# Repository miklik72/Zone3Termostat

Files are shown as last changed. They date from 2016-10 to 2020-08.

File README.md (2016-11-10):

# Zone3Termostat
3 zone wireless termostat with 433MHz sensors T25

In project based on Arduino UNO I'm using 3 wireless 433MHz sensors Sencor T25 for control one boiler by relay.
Possible is use 5 programs with 6 steps per day with own temperature. Implemented is also RTC for use real time.
Each zone is possible independent turn on or off. For zone is possible also set date and time for delay start.
Here is used also LCD1602 ROBO shiels with 5 buttons + reset.

For sensors T25 I'm using my own library  https://github.com/miklik72/SensorT25.

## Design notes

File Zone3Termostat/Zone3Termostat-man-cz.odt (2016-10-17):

1. Základní obrazovka Tlačítka

Set číslo pokoje teplota program topí

1

3

2

Zpět

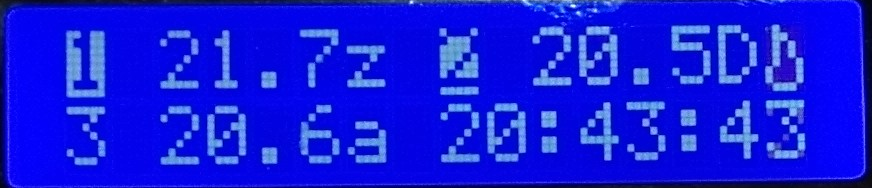
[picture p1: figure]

čas

  1. číslo pokoje: 1 – 3 , inverzně = zapnuto
  2. Teplota: teplota v pokoji v °C
  3. Program: a-e = pokoj netopí, A-E = pokoj topí, z = zpožděné zapnutí
  4. Topí: kotel je sepnutý
  5. Čas: aktuální čas

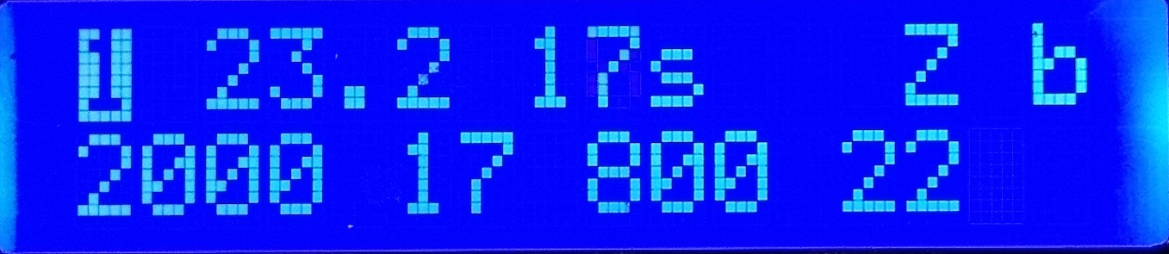
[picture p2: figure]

2. Nastavení pokoje
  1. Stiskni tlačítko čísla pokoje (1 – 3) pro obrazovku pokoje
  2. Zapnutí pokoje

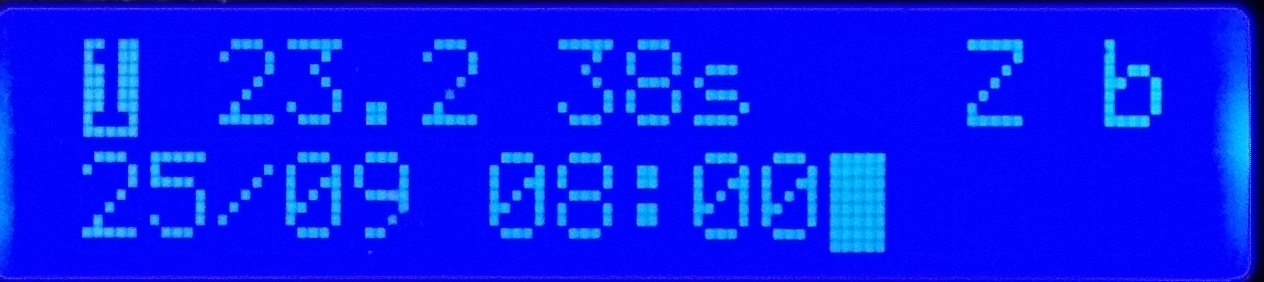
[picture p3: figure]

    1. Stiskni Set pro obrazovku zapnutí pokoje
    2. Stiskni Set pro zapnutí/vypnutí pokoje (číslo pokoje inverzně = zapnuto)
    3. Zpožděný start (volitelné) – pokoj bude zapnut ve zvolený den a čas, pokud je větší než současný čas, jinak zapne pokoj okamžitě.
      1. Nastav šipkami datum zpožděného zapnutí
      2. Nastav šipkou hodinu zpožděného sepnutí
      3. zpět na obrazovku pokoje (po 10s se přepne samo)
  3. Změna programu
    1. Vyber šipkami program vytápění a až e
      1. a – 6:00/23°, 10:00/21°, 15:00/23°, 23:00/20°
      2. b – 6:00/24°, 22:00/20°
      3. c - 22°
      4. d – 6:00/23°, 23:00/19°
      5. e – 24°

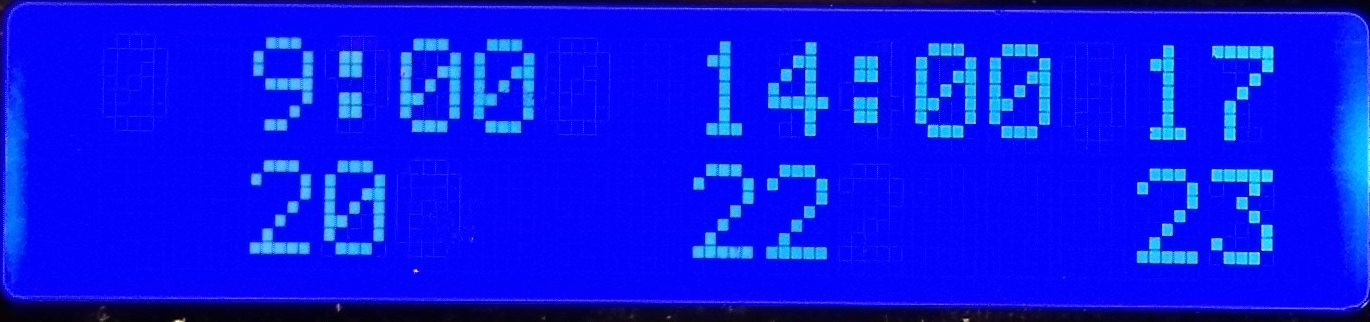
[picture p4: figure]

  4. Zobrazit programu
    1. Stiskni šipku nahoru
    2. Vrátí se samo do obrazovky pokoje
  5. zpět na hlavní obrazovku (po 10s se přepne samo)

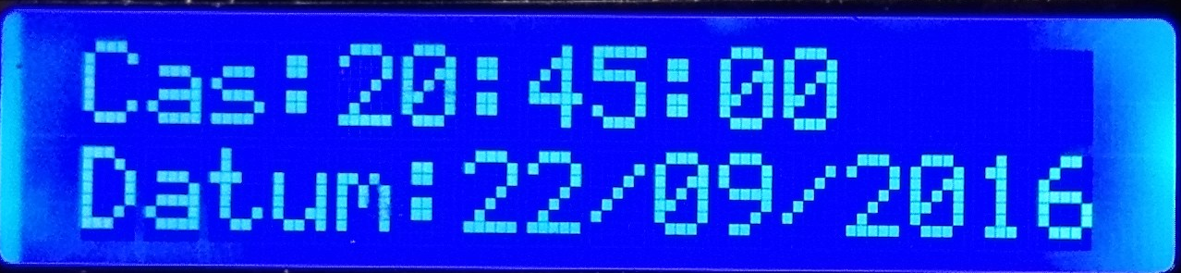
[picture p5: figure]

3. Nastavení hodin (pokud byl dlouho vypnutý proud)
  1. Stiskni Set pro obrazovku nastavení času
  2. Vyber šipkami nastavovanou hodnotu, bliká pod ní kurzor (hodiny, minuty, den, měsíc, rok)
  3. Nastav šipkami hodnotu
  4. Opakuj body 3.2 a 3.3 do nastavení správného času
  5. Stiskni Set – po 2s se zobrazí nápis SET
  6. Stiskni pro ukončení bez uložení nebo Set pro zápis času do hodin

obrazovka pokoje obrazovka zapnutí

pokoj teplota stáří teploty zpoždění program

aktuální krok programu následující krok datum a čas zpožděného zapnutí

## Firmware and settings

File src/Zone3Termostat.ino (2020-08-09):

#include <Arduino.h>
#include <Math.h>

/* 3 zone wireless termostat used 433Mhz temperature sensors T25
Martin Mikala (2016) dev@miklik.cz

v1.1.0 9.11.2016 - extension for set programs
v1.2.0 28.11.2016 - reset to initial state and EEPROM data structure version, more comments
v1.2.1 11.12.2016 - fix program set (validation for programs)
v1.3.0 1.1.2017 - open window detection
v1.3.1 1.1.2017 - fixed temperature history and calc heating
v1.3.2 3.1.2017 - added watchdog
v1.4.0 4.1.2017 - turn on/off extended functions (watchgod,OpenWindow)
v1.4.1 7.11.2017 - new DS3231 library
v1.4.2 23.12.2018 - set range time for delay time to 0-23
v1.4.3 17.12.2019 - change in SensorT25 lib , limit for temp 30C
v1.4.4 17.12.2019 - reset delay in new year 1.1. 00:00 and roll past delay to current time

todo:
1.5--   1.1.2017 - extra button for activate sensor
1.--- 18.12.2016 - debuging to serial console
1.---   1.1.2017 - merge{clean} variables c & s as c  - for channel or sensor and use s for program step
1.---   4.1.2017 - log to SD card
1.---   9.1.2017 - invalidate old temperatures (60 minutes)
2.---   1.1.2017 - add remote valve control
2.---   4.1.2017 - add ESP8266 Wifi Connection - control from WEB
----- 28.11.2016 - cut app to more libraries

Devices:
1x Arduino UNO
3x Sencor T25 433MHz sensor http://www.sencor.eu/wireless-sensor/sws-t25
1x RXB6 - 433MHz receiver
1x LCD keypad shield V0.1 LCD1602A+buttons
1x RTC DS3231
1x relay module HL-51 250V/10A
*/

// application version
#define APP_VERSION_MAIN 1
#define APP_VERSION_RELEASE 4
#define APP_VERSION_PATCH 4

#define DAY_STEP 6
#define PROGRAMS 5
#define MIN_TEMP 5
#define MAX_TEMP 30
#define UNFREEZ_TEMP MIN_TEMP - 2


// RF sensors https://github.com/miklik72/SensorT25/
#define IRQ_PIN 2      // RF input with irq
#define SENSORS 3
#include <SensorT25.h>

//LCD
#define PIN_RS 8     // arduino pin wired to LCD RS
#define PIN_EN 9     // arduino pin wired to LCD EN
#define PIN_d4 4     // arduino pin wired to LCD d4
#define PIN_d5 5     // arduino pin wired to LCD d5
#define PIN_d6 6     // arduino pin wired to LCD d7
#define PIN_d7 7     // arduino pin wired to LCD d8
#define PIN_BL 10    // LCD backlight control (see bug http://forum.arduino.cc/index.php?topic=96747.0)
#define SafeBLon(pin) pinMode(pin, INPUT)
#define SafeBLoff(pin) pinMode(pin, OUTPUT)
#define LCD_ROWS 2      // row of LCD
#define LCD_COLUMNS 16  // columns of LCD

// invert one
byte invert1[8] = {
  B11011,
  B10011,
  B11011,
  B11011,
  B11011,
  B11011,
  B10001,
  B11111,
};

// invert two
byte invert2[8] = {
  B10001,
  B01110,
  B11110,
  B11101,
  B11011,
  B10111,
  B00000,
  B11111
};

// invert three
byte invert3[8] = {
  B00000,
  B11101,
  B11011,
  B11101,
  B11110,
  B01110,
  B10001,
  B11111
};

// fire1
byte fire1[8] = {
	0b01000,
	0b01100,
	0b01010,
	0b01010,
	0b01001,
	0b10001,
	0b10001,
	0b01110
};

#include <LiquidCrystal.h>
// initialize the library with the numbers of the interface pins
LiquidCrystal lcd(PIN_RS,  PIN_EN,  PIN_d4,  PIN_d5,  PIN_d6,  PIN_d7);
byte lcdrow = 0;
byte lcdcol = 0;

//RTC I2C
#include <DS3231.h>
#include <Wire.h>
//DS3231 rtc(SDA,SCL);
DS3231 Clock;
RTClib rtc;
//Time t;
DateTime t;
unsigned int tmpYear;
byte tmpMonth;
byte tmpDate;
byte tmpHour;
byte tmpMinute;

//keypad
#include <DFR_KeyMM.h>
//DFR_KeyMM keypad(A0);               // A0 is wired in LCD keypad shield
DFR_KeyMM keypad;
int key;

//relay
#define RELAY_PIN 11
#define RELAY_DELAY 1000             // cheange relay state only every 1000 ms
long relay_oldtime = millis();

//EEPROM
#include <EEPROM.h>
#define EEPROM_VERSION 13
#define EEPROM_OFFSET 0                                   // ERRPROM OFFSET
#define EEPROM_OFFSET_VERSION EEPROM_OFFSET               // version of EEPROM data structure
#define EEPROM_OFFSET_DATA EEPROM_OFFSET + 1              // offset for data start
#define EEPROM_OFFSET_ACT EEPROM_OFFSET_DATA              // 1-3 ACTIVATED SENSORS    3B
#define EEPROM_OFFSET_PRG EEPROM_OFFSET_ACT + SENSORS     // 4-6 SENSORS PROGRAM      3B
#define EEPROM_OFFSET_DELAY EEPROM_OFFSET_PRG + SENSORS   // 7-15 DELAY DATE and HOUR  3x3B = DDMM+HH
#define EEPROM_OFFSET_PSET EEPROM_OFFSET_DELAY + 9       // 16 Termostat programs are in EEPROM 1B
#define EEPROM_OFFSET_PROGS EEPROM_OFFSET_PSET + 1       // 17 - 107 Termostat programs - 5x6x3B = 6 steps temperature + HHMM for programs
//EEPROM 11 extension for watchdog
#define EEPROM_OFFSET_BOOTS EEPROM_OFFSET_PROGS + (PROGRAMS * DAY_STEP * 3)  // 108-109 - boots counter 2B
#define EEPROM_OFFSET_BOOTTIME EEPROM_OFFSET_BOOTS + 2                       // 110-113 - boot time and date 4B
//EEPROM 12 extension for window open check
#define EEPROM_OFFSET_ACTWTDOG EEPROM_OFFSET_BOOTTIME + 4                   // 114 - active watchdog 1B
//EEPROM 13 extension for window open check
#define EEPROM_OFFSET_ACTWINDOW EEPROM_OFFSET_ACTWTDOG + 1                   // 114 - active window oen detection 1B
#define EEPROM_OFFSET_NEXT EEPROM_OFFSET_ACTWINDOW + 1                       // 1st free byte
boolean rom_change = false;

//watchdog
#include <avr/wdt.h>

//Application definition
  //LCD positions
    // Main screen
#define CH1_MAIN_R 0
#define CH1_MAIN_C 0
#define CH2_MAIN_R 0
#define CH2_MAIN_C 8
#define CH3_MAIN_R 1
#define CH3_MAIN_C 0
#define POS_TEMP 1
#define POS_STATE 6
#define T_MAIN_R 1
#define T_MAIN_C 8
#define H_MAIN_R 0
#define H_MAIN_C 15
    // Setup sensor screen
#define INF_SENS_R 0             //sensor static info row
#define CH_SENS_C 0
#define AGE_SENS_C 7
#define STATE_SENS_C 11
#define PRG_SENS_C 15
#define EXIT_TIME 10000           //time for automatic exit to main screen in ms
//#define MAX_TEMP 30               // Max temperature set
//#define MIN_TEMP 4                // Min temperature
    // Time set scree
#define TIME_ROW 0
#define TIME_HCOL 4
#define TIME_MCOL 7
#define TIME_SCOL 10
#define DATE_ROW 1
#define DATE_DCOL 6
#define DATE_MCOL 9
#define DATE_YCOL 12
byte cur_pos_c = TIME_HCOL;
byte cur_pos_r = TIME_ROW;

  // Control keys
#define KEYUP 3
#define KEYDOWN 4
#define KEYLEFT 2
#define KEYRIGHT 5
#define KEYSET 1

// watch heating issues
#define TEMP_HIST_STEPS 10                                  // keep 10 last tepm
#define TEMP_HIST_STEP 1                                    // time step for save temperature in minutes
#define TEMP_HIST_TIME TEMP_HIST_STEPS * TEMP_HIST_STEP     // whole time history keeping
#define DELTA_WINDOW_OPEN_C 1                               // temp delta for detect open window
#define DELTA_WINDOW_OPEN_TIME 5                            // time for detect open window in minutes
#define HEATING_PAUSE_WINDOW 30                             // how long will be heating stopped
#define DELTA_VALVE_CLOSE_C 1                               // temp delta for detect close valve
#define DELTA_VALVE_CLOSE_TIME 10                           // time for detect close valve in minutes
#define HEATING_PAUSE_VALVE 30                              // how long will be heating stopped in minutes
#define TEMP_LIMIT 1                                        // control temperature + - wanted temperature
bool active_window_pause = false;                            // activate window pause detection
float prg_temp_hist[SENSORS][TEMP_HIST_STEPS];              // temperature history for detect heating pause
long temp_hist_last_time = millis();                         // timestamp for calculate next temperature record
byte open_window[SENSORS]={0,0,0};                          // detect open window
byte close_valve[SENSORS]={0,0,0};                          // detect close valve
long open_window_time[SENSORS]={0,0,0};                     // detect open window
long close_valve_time[SENSORS]={0,0,0};                     // detect close valve

//next
#define PROG_SPACE 5                    // space between values in program screen


// Application variables
String act_screen = "main";
boolean sens_active[SENSORS]={false,false,false};         // is sensor control active
boolean sens_heating[SENSORS]={false,false,false};        // heating for sensor
byte sens_heating_pause[SENSORS]={0,0,0};                 // countdown heating stop when window open  or closed valve are detected, in minutes
boolean sens_heating_pause_active[SENSORS]={false,false,false};  // heating pause was activated
float sens_heating_pause_temp0[SENSORS]={0,0,0};          //save temperature when pause start
float sens_heating_pause_tempB[SENSORS]={0,0,0};          //save back related temperature for pause start
byte temp_back_step_window = (byte)ceil( (float)DELTA_WINDOW_OPEN_TIME / (float)TEMP_HIST_STEP);    // how old temp we are using for comparation if window is open
byte temp_back_step_head = (byte)ceil( (float)DELTA_VALVE_CLOSE_TIME / (float)TEMP_HIST_STEP);    // how old temp we are using for comparation if radiator head is closed, temperature is not growing
long sens_delay[SENSORS][3]={{0,0,0},{0,0,0},{0,0,0}};    // activate sensor delay DDMMHH (Day Month Hour)
boolean heating = false;                                  // control relay for turn on/off heating
byte sens_prg[SENSORS]={2,3,1};                           // number of program for sensor
long time_min_count = millis();                           // variable fo count heating pause
bool active_watchdog = true;                              // activate watchdog

const byte init_temp[PROGRAMS][DAY_STEP] =                // temperature for programs
{
  {23,21,22,20,0,0},
  {22,20,0,0,0,0},
  {21,0,0,0,0,0},
  {23,20,0,0,0,0},
  {22,19,0,0,0,0}
};
const unsigned int init_time[PROGRAMS][DAY_STEP] =        // time points for programs
{
  {600,1000,1500,2200,0,0},                              // number format HHMM, 0 = off
  {600,2300,0,0,0,0},
  {100,0,0,0,0,0},
  {600,2300,0,0,0,0},
  {600,2200,0,0,0,0}
};
byte prg_temp[PROGRAMS][DAY_STEP] =                           // temperature for programs
{
    {23,21,22,20,0,0},
    {22,20,0,0,0,0},
    {21,0,0,0,0,0},
    {23,20,0,0,0,0},
    {22,19,0,0,0,0}
};
unsigned int prg_time[PROGRAMS][DAY_STEP] =        // time points for programs
{
    {600,1000,1500,2200,0,0},                              // number format HHMM, 0 = off
    {600,2300,0,0,0,0},
    {100,0,0,0,0,0},
    {600,2300,0,0,0,0},
    {600,2200,0,0,0,0}
};

unsigned long deltime = 0;
boolean refreshtime = false;

/*****************************************************************************
*
*                          SETUP / LOOP
*
******************************************************************************/
void setup()
{
  //Serial console
  Serial.begin(9600);
  // RF sensors
  SensorT25::enable(IRQ_PIN);

  //RTC
  //rtc.begin(); new lib
  Wire.begin();

  //LCD
  // set up the LCD's number of columns and rows
  lcd.createChar(0, invert1);
  lcd.createChar(1, invert2);
  lcd.createChar(2, invert3);
  lcd.createChar(7, fire1);
  //lcd.createChar(8, invert1);
  //lcd.createChar(8, fire2);
  lcd.begin(16, 2);
  SafeBLoff(PIN_BL);
  delay(100);
  SafeBLon(PIN_BL);
  lcd.setCursor(0, 0);
  lcd.print("3ZoneTermostat");
  lcd.setCursor(0, 1);
  lcd.print("by Martin Mikala");
  delay(500);
  lcd.clear();
  lcd.setCursor(0, 0);
  lcd.print("v");
  lcd.print(APP_VERSION_MAIN);
  lcd.print('.');
  lcd.print(APP_VERSION_RELEASE);
  lcd.print('.');
  lcd.print(APP_VERSION_PATCH);
  lcd.print("_");
  lcd.print(EEPROM_VERSION);
  lcd.setCursor(0, 1);
  lcd.print("B:");
  lcd.print(eeprom_read_boots());
  lcd.print(" T:");
  lcd.print(eeprom_read_boottime());

  delay(1500);
  lcd.clear();

  //relay
  pinMode(RELAY_PIN, OUTPUT);

  //EEPROM
  eeprom_init();
  //eeprom_init_progs();
  eeprom_load();

  //watchdog
  wdt_enable(WDTO_4S);  // watchdog counter to 4s

  //init variable
  //reset_temp_hist_all();
  //new boot, write info
  new_boot();
}

void loop()
{
    wdt_reset();
    calc_heating();
    set_relay();
    temp_history();

    key = keypad.getKey();
    switch (key)
    {
        case KEYLEFT:
          sensor_set(0);                   // convert char of number to byte
          break;
        case KEYUP:
          sensor_set(1);                   // convert char of number to byte
          break;
        case KEYRIGHT:
          sensor_set(2);                   // convert char of number to byte
          break;
        case KEYSET:
          //set_termostat();
          set_termostat2();
          break;
    }
      if(lcd_refresh()) print_main_screen();

}

/*****************************************************************************
*
*        functions for recognize open window or closed radiators valve
*
******************************************************************************/

// execute every TEMP_HIST_STEP
void temp_history()
{
    // execute with history step time
    if(delta_minutes(temp_hist_last_time) >= TEMP_HIST_STEP)
    {
        save_temp_history();
        if (active_window_pause) checkHeatingPause();
        sprint_temp_hist();

        temp_hist_last_time = millis();
    }

    //execute every minutes
    if(delta_minutes(time_min_count) >= 1)
    {
        countdownHeatingPause();

        time_min_count = millis();
    }

}

void sprint_temp_hist()
{
    Serial.print("TEMP HIST:");
    //Serial.println(rtc.getTimeStr()); new lib
    t = rtc.now();
    Serial.print(t.hour(), DEC);
    Serial.print(':');
    Serial.print(t.minute(), DEC);
    Serial.print(':');
    Serial.print(t.second(), DEC);
    Serial.println();
    for(byte s = 0;s < SENSORS;s++)
    {
        Serial.print(s);
        Serial.print('-');
        for(byte i = 0;i < TEMP_HIST_STEPS;i++)
        {
            Serial.print(i);
            Serial.print('_');
            Serial.print(prg_temp_hist[s][i]);
            Serial.print(',');
        }
        Serial.print(" T ");
        Serial.print(SensorT25::getTemperature(s));
        Serial.print(" - ");
        Serial.print(getProgTempCurrent(s));
        Serial.print(" W ");
        Serial.print(temp_back_step_window);
        Serial.print(" - ");
        Serial.print(prg_temp_hist[s][temp_back_step_window] - prg_temp_hist[s][0]);
        Serial.print(" - ");
        Serial.print(isWindowOpen(s));
        Serial.print(" , V ");
        Serial.print(temp_back_step_head);
        Serial.print(" - ");
        Serial.print(prg_temp_hist[s][temp_back_step_head] - prg_temp_hist[s][0]);
        Serial.print(" - ");
        Serial.print(isHeadClose(s));
        Serial.print(" : ");
        Serial.print(sens_heating_pause[s]);
        Serial.print(" - ");
        Serial.print(sens_heating[s]);
        Serial.println();
    }

}

//save few last temperatures for sensors in interval
void save_temp_history()
{
    shift_temp_hist();
    for(byte s = 0;s < SENSORS;s++)
    {
        prg_temp_hist[s][0] = SensorT25::getTemperature(s);
    }
}

// rotate temperature history
void shift_temp_hist()
{
    for(byte s = 0;s < SENSORS;s++)
    {
        for(byte i = TEMP_HIST_STEPS - 1;i > 0;i--)
        {
            prg_temp_hist[s][i] = prg_temp_hist[s][i-1];
        }
    }
}

// calc minutes from parameter time
unsigned int delta_minutes(unsigned long last_lime)
{
    unsigned long ctime = millis();
    unsigned long delta_time = (last_lime < ctime) ? ctime - last_lime : ctime + !(last_lime) + 1;
    return millis2min(delta_time);
}

// convert miliseconds to minutes
int millis2min(long m)
{
    return m/60000;
}

// reset all temperature history
void reset_temp_hist_all()
{
    for(byte s = 0; s < SENSORS; s++)
    {
            reset_temp_hist(s);
    }
}

// reset one sensor history
void reset_temp_hist(byte s)
{
        for(byte i = 0;i < TEMP_HIST_STEPS;i++)
        {
            prg_temp_hist[s][i] = 0.0f;
        }
}

//check is temperature go down for room where is heating
boolean isWindowOpen(byte s)
{
        // true if delta temp is larger then treshold and older temp is not 0
        if((prg_temp_hist[s][temp_back_step_window] != 0) && (prg_temp_hist[s][temp_back_step_window] - prg_temp_hist[s][0]) > DELTA_WINDOW_OPEN_C)
        {
            return true;
        }
        else return false;
}

//check is temperature go down for room where is heating
boolean isHeadClose(byte s)
{
        // true if delta temp is smaller then treshold and comparasion temperature is not 0
        if((prg_temp_hist[s][temp_back_step_head] != 0) && ((prg_temp_hist[s][temp_back_step_head] - prg_temp_hist[s][0]) < DELTA_VALVE_CLOSE_C) && (getProgTempCurrent(s) - TEMP_LIMIT > SensorT25::getTemperature(s)))
        {
            return true;
        }
        else return false;
}


// set it only if room is heating and heatin pause is not set and delta temp is larger then treshold
void setHeatingPause(byte s)
{
    Serial.print("BP setHP "); Serial.print(s); Serial.print(' ');
    if(sens_heating[s] && (sens_heating_pause[s] == 0) && isWindowOpen(s))
    {
        Serial.print("true W");
        sens_heating_pause[s] = HEATING_PAUSE_WINDOW;
        //sens_heating_pause_temp0[s] = prg_temp_hist[s][0];                  //save temperature when pause start
        //sens_heating_pause_tempB[s] = prg_temp_hist[s][temp_back_step_window];     //save back related temperature for pause start
        sens_heating_pause_active[s] = true;                                   // pause is activated
    }
    /*
    if(sens_heating[s] && (sens_heating_pause[s] == 0) && isHeadClose(s))
    {
        Serial.print("true V");
        sens_heating_pause[s] = HEATING_PAUSE_VALVE;
        sens_heating_pause_temp0[s] = prg_temp_hist[s][0];                  //save temperature when pause start
        sens_heating_pause_tempB[s] = prg_temp_hist[s][temp_back_step_window];     //save back related temperature for pause start
        sens_heating_pause_active[s] = true;                                   // pause is activated
    }
    */
}

// check all sensors for heating pause
void checkHeatingPause()
{
    for(byte s = 0; s < SENSORS; s++)
    {
            setHeatingPause(s);
    }
}

// count down heating pauses
void countdownHeatingPause()
{
    for(byte s = 0; s < SENSORS; s++)
    {
        if(sens_heating_pause[s] != 0)
        {
            sens_heating_pause[s]--;
        }
        // turn of heatin pause status and reset history
        if(sens_heating_pause[s] == 0 && sens_heating_pause_active[s] == true)
        {
            sens_heating_pause_active[s] = false;
            reset_temp_hist(s);
        }
    }
}

// get if is sensor paused
boolean isSensorPaused(byte s)
{
    return (sens_heating_pause[s] > 0) ? true :false;
}

/*****************************************************************************
*
*                           EEPROM functions
*
******************************************************************************/


//check EEPROM data structure version and initialize it or migrate
void eeprom_init()
{
    byte eeprom_version = EEPROM.read(EEPROM_OFFSET_VERSION);           // read EEPROM version from eeprom
    if(eeprom_version == 0 || eeprom_version == 255)                    // default init value in EEPROM, format EEPROM to initial state
    {
        //eeprom_format(eeprom_version);
        eeprom_format();
    }
    else if (eeprom_version < EEPROM_VERSION)                          // new EEPROM data structure version
    {
        if(eeprom_version < 12)
        {
            eeprom_format_boot();   // chnage word dword read/write EEPROM by eeprom.h function
        }
        eeprom_set_version();
    }
    else if (eeprom_version > EEPROM_VERSION)                          // older EEPROM data structure version
    {
        //eeprom_format(eeprom_version);
        eeprom_set_version();
    }
}

// format EEPROM to initial state and values
//void eeprom_format(byte v)
void eeprom_format()
{
    eeprom_format_act();
    eeprom_format_prg();
    eeprom_format_delay();
    eeprom_format_progs();
    eeprom_format_boot();
    eeprom_set_version();
}

// set initial active values for sensors to false
void eeprom_format_act()
{
    for(byte s = 0; s < SENSORS;s++)
    {
      EEPROM.write(EEPROM_OFFSET_ACT + s,0);
    }
}

// set initial program for sensors to 0 = a
void eeprom_format_prg()
{
    for(byte s = 0; s < SENSORS;s++)
    {
      EEPROM.write(EEPROM_OFFSET_PRG + s,0);
    }
}

// reset delay date for sensors
void eeprom_format_delay()
{
    for(byte s = 0; s < SENSORS;s++)
    {
      for(byte i = 0; i < 3;i++)
      {
       EEPROM.write(EEPROM_OFFSET_DELAY + (s * 3) + i,0);
      }
    }
}

// set initial values for programs 0-4 or a-e
void eeprom_format_progs()
{
    for(byte p = 0;p < PROGRAMS;p++)
    {
        eeprom_reset_progs(p);
    }
    EEPROM.write(EEPROM_OFFSET_PSET, 1);
}

// set initial values for booting log
void eeprom_format_boot()
{
    eeprom_write_boots(0);
    eeprom_write_boottime(0);
}

// set EEPROM structure version
void eeprom_set_version()
{
    EEPROM.write(EEPROM_OFFSET_VERSION, EEPROM_VERSION);
}

//set initial values for program
void eeprom_init_progs()
{
    if(EEPROM.read(EEPROM_OFFSET_PSET) != 1)
    {
        eeprom_format_progs();
    } else
    {
        for(byte p = 0;p < PROGRAMS;p++)
        {
            eeprom_load_progs(p);
        }
    }
}

// load programs values from EEPROM
void eeprom_load_progs(byte p)
{
    for(byte s = 0;s < DAY_STEP;s++)
    {
        prg_temp[p][s] = EEPROM.read(EEPROM_OFFSET_PROGS + (p * DAY_STEP * 3) + (s * 3));
        prg_time[p][s] = EEPROM.read(EEPROM_OFFSET_PROGS + (p * DAY_STEP * 3) + (s * 3) + 1) * 100;
        prg_time[p][s] += EEPROM.read(EEPROM_OFFSET_PROGS + (p * DAY_STEP * 3) + (s * 3) + 2);
    }
}

// write programs to EEPROM
void eeprom_write_progs(byte p)
{
    for(byte s = 0;s < DAY_STEP;s++)
    {
        EEPROM.write(EEPROM_OFFSET_PROGS + (p * DAY_STEP * 3) + (s * 3), prg_temp[p][s]);
        EEPROM.write(EEPROM_OFFSET_PROGS + (p * DAY_STEP * 3) + (s * 3) + 1, prg_time[p][s] / 100);
        EEPROM.write(EEPROM_OFFSET_PROGS + (p * DAY_STEP * 3) + (s * 3) + 2, prg_time[p][s] % 100);
    }
}
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

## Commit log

2016-09-18 kezpad library tunning for prevent double pushes
    [Zone3Termostat.ino]
2016-09-19 Fix keypad library for oscillation Set autoexit from menu - senstor state, time seting
    [Zone3Termostat.ino]
2016-09-19 Use keypad class with default PIN A0
2016-11-01 Add schema in Fritzing
    [3ZoneTermostat_v0.4.0.fzz]
2016-11-01 Revert "small comment change"
    This reverts commit cf33c780cc43a6859dcefd90dec39ed5fff5c300.
    [Zone3Termostat.ino]
2016-11-01 Change temperature program
2016-11-02 Add setings for set temperature in program, part 1
2016-11-09 Programs in EEPROM and temperature setting (missing time setting in programs)
    [Zone3Termostat.ino]
2016-11-09 Add extension for set program temperature and time and keep it in EEPROM.
2016-11-09 fix date for version 1.1
    [Zone3Termostat.ino]
2016-11-09 new version 1.2 open window and close valve detection
2016-11-10 Start work on detect open vindow or close valve
2016-11-25 fixed problem with _treshold in library DFR_KeyMM
    [Zone3Termostat.ino]
2016-11-28 v1.2.0 a1 - fix condition for UP key in program seting increate key delay to 100ms
    [Zone3Termostat.ino]
2016-12-11 v1.2.1 11.12.2016 - fix program set (validation for programs)
    [Zone3Termostat.ino]
2017-01-01 Added window open detection with heating pause
2017-01-01 1.3.1 add missing code for calc_heating function
    [Zone3Termostat.ino]
2017-01-01 fix - add isSensorPaused to calc_heating
    [Zone3Termostat.ino]
2017-01-03 v1.3.1 - fixed temperature history and calc heating
    [Zone3Termostat.ino]
2017-01-03 v1.3.2 - add watchdog + reset points and part of boot log into EEPROM
    [Zone3Termostat.ino]
2017-01-03 v1.3.2b - add function for save boot time, reset for EPPROM11 and newer, use eeprom lib read/write word dword function.
    [Zone3Termostat.ino]
2019-01-07 Changes for new SensorT25 library and condition set iqr for ESP and AVR
2019-12-17 v1.4.3 - in SensorT25 lib added ltemperature imit to 30C
